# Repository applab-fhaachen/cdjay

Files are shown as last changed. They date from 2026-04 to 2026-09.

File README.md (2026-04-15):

# CDjay

## Introduction
The success of Pioneer's CDJ-Players is based on their usability and performance-oriented controls. And while the technology has evolved from CDs over SD-Cards to USB-Keys or direct interaction with a laptop, the control interface itself hasn't changed much. 
Modern CDJs, such as the CDJ-850, CDJ-900, CDJ-2000, and newer offer the possibility to directly connect to a host software, such as Algoriddim DJay, Native Instruments' Traktor, Serato Scratch, in order to be used as controller. 
The goal of this project is to bring this capability to older CDJ-Models in order to keep their control interface. 

## Related Work
A number of other projects have looked at the same idea. Some turning the CDJ into a MIDI-based controller, others integrating a RaspberryPi and running Mixxx, and open source DJ-Software on it, essentially turning them into full-blown, standalone, media-players. 

## USB-HID
The key is the USB-HID protocol which the newer models provide. Instead of registering as a USB-Midi Device, they have their own, proprietary protocol. While this conflicts with the idea of an open and flexible interface, it has the advantage of providing bi-directional communication, and thus, be able to show additional information directly on the display of the CDJ. The most common DJ software supports the HID protocol.

### Details
Technically, the CDJ registers as a USB device with a number of endpoints:
- The USB-HID interface for the control messages.
- a USB-audio interface for audio-output from the CDJ itself (relevant if you don't use the internal mixer of the software, but an external mixer). 

## Interface
Since we want to focus on interfacing the old CDJs with the modern world (USB-C, Software, etc.), we use iPad mini running Algoriddim's djay in single deck mode, which gives us all the benefits such as touch interaction, integration to streaming services, etc.. Any iPad being able to run djay is fine, although interfacing is easier with the usb-c models. 

### Installation
Install djay from the App-Store on your iPad. Technically, it is possible to run djay from an iPhone, however, it doesn't support single-deck mode on smaller devices. 

### Connecting
If you have an iPad with a lightning-connector, you need a lightning to usb-converter that supports USB OTG. This will make the iPad the host of your USB connection, and the CDJay the client. 
For the USB-Models, just connect the USB-C connection to your iPad. 

## Acknowledgements

This project was supported by...

## License
MIT License

All trademarks are property of their respective owners. This project is part of the education at FH Aachen University of Applied Sciences and not affiliated to any of the brand names.

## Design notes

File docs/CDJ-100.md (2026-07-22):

# CDJ-100
## Intro

## Board Analysis
All CDJ-100 controls (buttons, sliders, etc.) are mounted on a board that sits in the top half of the shelf and is connected to the mainboard through a 36-Pin flex cable. 

The service manual lists the following pin labels:
CN701 - CN601
Pin | I/O | Description | Use?
----|-----|-------------|-----
1  |  -  | V+5V |
2  |  I  | ADIN | Pitch slider voltage input.
3  |  I  | CT | Slider center tap voltage input.
4  | _ | GNDD|
5  | I | JOG1 | Jog Wheel Encoder. V+5V -> GNDS. Interrupt input for jog dial pulses
6  | I | JOG2 | Jog Wheel Encoder. Jog dial pulse input
7  | I |KD2 | Key return lines. Pulled High when one of the switches is pressed
8  | I | KD1 |
9  | I | KD0 |
10 | O | S12 | FL segment output
11 | O | S1 | FL segment output To HOLD (KD0), TRKB (KD1), Play (KD2) switch
12 | O | S2 | To TIME (KD0), TRKF (KD1), CUE (KD2) switch
13 | O | S3 | To EJECT (KD0), JET (KD1), SCNB (KD2) switch 
14 | O | S4 | To MT (Master Tempo) (KD0), ZIP (KD1), SCNF (KD2) switch  Connected to Flip-Flop for LED on/off
15 | O | S5 | WAH Switch to KD1
16 | O | S6 |
17 | O | S7 |
18 | O | S8 | Connected to Flip-Flop for LED on/off
19 | O | S9 | Connected to Flip-Flop for LED on/off
20 | O | S10 |
21 | O | S11 |
22 | O | G11 | FL grid output 
23 | O | G10 |
24 | O | G9 | FL grid output  
25 |  O | G8 | 
26 |  O | G7 |
27 |  O | G6 |
28 |  O | G5 |
29 |  O | G4 |
30 |  O | G3 |
31 |  O | G2 |
32 |  O | G1 | Clock Input for Flip-Flop
33 |  - | V-BV | Voltage for the Play/Cue/Disc/Window LEDs
34 |  - | AC2 | AC Voltage for the LCD (Either 5V AC or 3V AC)
35 | - | GNDS |
36 | - | AC1 | AC Voltage for the LCD

To control all that, we need 

| No.| Purpose | 
| -- | -- |
| 1  |  ADC Input| 
| 1 | CT line
| 2 | Jog Wheel |
| 3 | Button Input | 
| 11 | G-Lines |
| 12 | S-Lines | 
|  | |
| 30 | Sum | 

### Switches: 
There are 13 switches in total

S601: TRACK SEARCH (<<)
S602: SEARCH (<<)
S603: PLAY/PAUSE 
S604: TRACK SEARCH (>>)
S605: SEARCH (>>)
S606: CUE
S607: DIGITAL JOG BREAK (JET)
S608: MASTER TEMPO
S609: DIGITAL JOG BREAK (ZIP)
S610: DIGITAL JOG BREAK (WAH)
S611: EJECT 
S613: TIME MODE/AUTO CUE
S615: DIGITAL JOG BREAK (HPLD)

The Transformer Board Assembly has the following outputs:
CN705
Pin | Description | Use?
----|-------------|-----
1  | AC2 |
2  | AC1 |
3  | VLOAD | -31V for the VFD controller
4  | Audio R| The Audio connectors are located on the Transformer Board,
5  | GNDA | The Audio connectors are located on the Transformer Board,
6  | Audio L | The Audio connectors are located on the Transformer Board,
7  | CONT2 | Control Port Pins
8  | CONT1 | Control Port Pins (for Fader Start etc.)
9  | V+5V |
10 | GNDD |
11 | /RST | Comes straight from the 5V regulator output, keeps MCU off until power is stable
12 | V+BV |
13 | GNDS |
14 | V-BV |

## Display
### Pin Connection
| Pin No. | 1  | 2  | 3  | 4  | 5  | 6  | 7  | 8  | 9  | 10 | 11 | 12 | 13  | 14  | 15 | 16 | 17 | 18 | 19 | 20 | 21 | 22 | 23 | 24 | 25 | 26 | 27 | 28 | 29 | 30 | 31 | 32 | 33 | 34 | 35 | 
|---|----|----|----|----|----|----|----|----|----|----|----|----|-----|-----|----|----|----|----|----|----|----|----|----|----|----|----|----|----|----| ----|----|----|----|----|----|
| Assignment | F1 | F1 | NP | S1 | S2 | S3 | S4 | S5 | S6 | S7 | S8 | S9 | S10 | S11 | S12 | S13 | S14 | S15 | NL | NL | NL | G1 | G2 | G3 | G4 | G5 | G6 | G7 | G8 | G9 | G10 | G11 | NP | F2 | F2 |
| Signal | AC1 | AC1 | | S1 | S2 | S3| AC2 | S4 | S5 | S6 | S6 | S7 | S8 | S9 |  S3 | S10 | S11 | S12 |  NL | NL | NL | G1 | G2 | G3 | G4 | G5 | G6 | G7 | G8 | G9 | G10 | G11 | NP | AC2 | AC2 |

- F1, F2: Filament 
- S1 to S15: Anode 
- NL: No Lead
- G1 to G11: Grid
- NP: No pin

## Working Principle

### Switches
The switches are read through multplexing using the lines S1-5 as Outputs and KD0-2 as Inputs.
To figure out which switch is pressed, pull S1 high, read KD0-3, set S1 log, set S2 high, read KD0-3, set S2 Low,...

So far so good. But at the same time S1-15 are also used to drive the display, so all that needs to work with quite some refresh rate. That should be measureable by probing G1 with an oscilloscope. Yes it is, ~100Hz

### Display

The display in the CDJ-100 is a Vacuum Fluorescent Display (VFD) and these are a bit different than an LCD, which is why we need a special controller. 

The display is split in 11 grids with 12 segments.
The G1-G11 lines are used to activate the respective Grid, whose value can then be set using the S1-12 lines. Since we don't have 15, but only 12 S-Lines there needs to be a trick somewhere. 
Pin 6 and Pin 15 (S3 & S12) share the same signal S3 to form a vertical line on the 14-segment characters (G3 to G8).
Pin 10 and 11 (S7 & S8)  share the same signal S6 form a horizontal line on the 14-segment characters (G3 to G8).

Driving a VFD requires some unusual voltages. While enabling a segment is done by applying +5V, it is immediately disabled again by applying a negative bias voltage to increase contrast. The original display driver uses -30V as bias voltage. 

The PT6302 Dislpay Driver IC [Info](https://support.newhavendisplay.com/hc/en-us/articles/4414910103063-PT6302) [Datasheet](https://support.newhavendisplay.com/hc/en-us/article_attachments/4414910097047) seems to be the right choice as it offers 16 Grids and 64 Segments. The PT6312 is cheaper but can only drive 11 groups with 11 segments max, while we need 11 groups with 12 segments. 

There are some libraries out there to use these chips.
https://github.com/the-real-mcarn/PT6302
https://github.com/ysard/PT6312_VFD_Arduino_Library

The LC75710 is also a good candidate. 

The -30V Bias Voltage, luckily, comes from the trans board assy as VLOAD.

Level Conversion between RPI and Display Controller TXS0108E

#### Synchronizing with the chip for multiplexing the button readout

We need a way to synchronize with the chip in order to read out the KD-Lines. We cannot do that in parallel since the Values on the S1 to S5 depend on what's going to be shown on screen. 

However, we have some unused G-Lines from the PT6302 which we can use as trigger on the RPi. If we connect these to inputs, and set the S-Lines accordingly, we can get an interrupt, read KD0-2 and be happy. We have 16 Group outputs on the PT6302, of which only 11 are used for the display. The remaining 5, G12-G16, are connected to the RPi (don't forget the Diodes). We set the content of these groups to fixed outputs, i.e., for G12 only S1 is enabled, for G13 only S2 is enabled, ..., for G16 only G5 is enabled. This contradicts the idea of multiplexing to save pins a bit, but since we don't have a direct synchronization between the display controller and the RPi, this seems like a feasible solution. 

### LEDs
The LEDs are controlled through line S4, S8, S9 and group 1. The trick here, is that in group 1, these lines are not used, therefore ignored and can thus be used to drive the LEDs. The according segments need to be enabled disabled in the display driver. 

### Pitch Fader
The pitch fader is a classical adjustable voltage divider. At minimum, the output voltage ADIN is 0V, whereas at maximum, it is +5V. The neutral position (0%) is important in order to play tracks at their original speed. In order to compensate possible fader drift through ageing, the circuit has the CT-output. This returns a constant voltage. Connect this to an ADC to have the exact reference for ADIN at the neutral position. 

The VREF for the ADC is +5V. The GNDREF for the ADC is GNDD. 

## Connections:

I2S - Audio
SPI - Display
Encoder 
Jog-Wheel 
Pitch-Fader
KDO-KD2

### Fader Start Control
• Standard CD trigger format
° ⅛" (3.5 mm) mini TRS jacks
° Start pulse on Tip.
° Stop pulse on Ring/Sleeve.
° Normally high – Active low.
° Pulse width is 20 ms.
° Start threshold is at –65 dB of control attenuation.
° Stop threshold is at –75 dB of control attenuation.

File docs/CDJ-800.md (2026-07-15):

# CDJ-800

## Introduction
The CDJ-800 MK2, unlike the CDJ-100, but like the 200, has a dedicated board with an own controller for the switches, jog dial etc. This means that we do not need to implement an own controller circuit, but can 'just' communicate with the interface board.

## Mainboard Connectors
The Mainboard has two connectors for the CD-Player. These are not relevant for our project. We could think of adding connectors just to not have them dangling around. 
- CN102 for the spindle motor
- CN101 towards CN1101
The MAIN ASSY has two connectors relevant for our endeavour. CN301 (CD53) to the SECB ASSY and CN701 (CN801) to the JACK ASSY.

### CN301 (CK4192 - - TBB, 1MM Pitch FFC ZIF)
Pin | I/O | Description | Use?
----|-----|-------------|-----
1  |  -  | V+7M |
2  |  -  | V+7M | 
3  |  -  | V+7M | 
4  | - | GNDM |
5  | - | GNDM | 
6  | - | GNDM | 
7  | - | V+8A | (Comes from CN701) 
8  | - | V+3D |
9  | - | V+3D |
10 | - | GNDD | 
11 | - | GNDD | 
12 | - | GNDD | 
13 | - | GNDD | 
14 | - | GNDD | 
15 | - | V+6B | 
16 | - | GNDS |
17 | - | V+5P |
18 | I/O | JSDATA | 
19 | I | TSDI | Data IN
20 | I | RMIN |
21 | O | TSCS | Cable Select
22 | I/O | CONT1 | 
23 | O | TSDO | Data Out
24 | I/O | CONT2 | 
25 |  O | TSCLK | Clock

### CN701 (CK4176 - - TBB, 1MM Pitch FFC ZIF)
Pin | I/O | Description | Use?
----|-----|-------------|-----
1  |  O  | LOUT | Left audio output channel
2  |  -  | GNDA | Audio Ground
3  |  -  | GNDA | 
4  |  O  | ROUT | R audio output channel
5  | - | V+8A | 
6  | O | MUTE | Mutes the audio output
7  | -  | V-7A | 
8  | O | GNDDOUT | GND for digital audio output
9  | O | DOUT | Digital audio outpout

### Power Supply

What we we need: and I think that all comes from external, so we don't need to generate anything. (See Page 20)
V+7M 
V+8A
V+3D
V+6B
V+5P

On the regulator board, there are two ICs: IC92 and IC91. 
IC91: Takes V+6B and delivers V+3D
IC92: Takes V+10B and delivers V+7A

### References
[https://forum.arduino.cc/t/hacking-cdj800-display-communication-protocol/1133083?page=3]
[https://www.youtube.com/@edescrambler/videos]
[https://github.com/djgreeb/CDJ-1000mk3_new_life_project/blob/master/Reverse%20Engineering%20Pioneer%20CDJ-1000%20serial%20protocol.pdf]

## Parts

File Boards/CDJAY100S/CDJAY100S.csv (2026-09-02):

Reference | Qty | Value | DNP | Exclude from BOM | Exclude from Board | Footprint | Datasheet
C1,C4,C12,C13,C17,C21,C22,C23,C24 | 9 | 100 n |  |  |  | Capacitor_SMD:C_1206_3216Metric_Pad1.33x1.80mm_HandSolder
C2,C3 | 2 | 10 u |  |  |  | Capacitor_SMD:C_1206_3216Metric_Pad1.33x1.80mm_HandSolder
C5,C6 | 2 | 100 u |  |  |  | Capacitor_SMD:C_1206_3216Metric_Pad1.33x1.80mm_HandSolder
C11 | 1 | 100 n
C14,C15 | 2 | 2.2 u |  |  |  | Capacitor_SMD:C_1206_3216Metric_Pad1.33x1.80mm_HandSolder
C16 | 1 | 1 u |  |  |  | Capacitor_SMD:C_1206_3216Metric_Pad1.33x1.80mm_HandSolder
C19,C20 | 2 | 100 p |  |  |  | Capacitor_SMD:C_1206_3216Metric_Pad1.33x1.80mm_HandSolder
CN701 | 1 | 52492-3620 |  |  |  | 52045-3645:ConnectorFPC&FFC_MOL52045-3645-36P_1
CN705 | 1 | 52151-1410 |  |  |  | Connector_PinHeader_2.00mm:PinHeader_1x14_P2.00mm_Vertical
CR2 | 1 | MBR120VLSFT1G |  |  |  | Diode_SMD:Nexperia_CFP3_SOD-123W | MBR120VLSFT1G
D8,D9,D10,D11,D12,D13,D14,D15,D16 | 9 | 1SS355VM |  |  |  | Diode_SMD:Nexperia_CFP3_SOD-123W | https://fscdn.rohm.com/en/products/databook/datasheet/discrete/diode/switching/1ss355vmte-17-e.pdf
i2S_Audio1 | 1 | PCM5102 |  |  |  | Package_SO:TSSOP-20_4.4x6.5mm_P0.65mm | http://www.ti.com/lit/ds/symlink/pcm5102.pdf
J1 | 1 | Rotary Encoder |  |  |  | Connector_PinHeader_2.54mm:PinHeader_1x05_P2.54mm_Vertical
R1,R5,R9,R10,R11,R18 | 6 | 10 k |  |  |  | Resistor_SMD:R_1206_3216Metric_Pad1.30x1.75mm_HandSolder
R2,R6 | 2 | 20 k |  |  |  | Resistor_SMD:R_1206_3216Metric_Pad1.30x1.75mm_HandSolder
R3,R4 | 2 | 5 k |  |  |  | Resistor_SMD:R_1206_3216Metric_Pad1.30x1.75mm_HandSolder
R7,R8,R14,R15,R21,R22,R32,R33,R34 | 9 | 10k |  |  |  | Resistor_SMD:R_1206_3216Metric_Pad1.30x1.75mm_HandSolder
R12,R13 | 2 | 2k |  |  |  | Resistor_SMD:R_1206_3216Metric_Pad1.30x1.75mm_HandSolder
R16,R19 | 2 | 1 k |  |  |  | Resistor_SMD:R_1206_3216Metric_Pad1.30x1.75mm_HandSolder
R17 | 1 | 470 |  |  |  | Resistor_SMD:R_1206_3216Metric_Pad1.30x1.75mm_HandSolder
R20 | 1 | 82 k |  |  |  | Resistor_SMD:R_1206_3216Metric_Pad1.30x1.75mm_HandSolder
R23 | 1 | 22k |  |  |  | Resistor_SMD:R_1206_3216Metric_Pad1.30x1.75mm_HandSolder
R24,R25,R26,R27,R28,R29,R30,R31 | 8 | 22k |  |  | Excluded from board | Resistor_SMD:R_1206_3216Metric_Pad1.30x1.75mm_HandSolder
rPi1 | 1 | RaspberryPi_Pico |  |  |  | Module:RaspberryPi_Pico_Common_Unspecified | https://datasheets.raspberrypi.com/pico/pico-datasheet.pdf
U1 | 1 | PT6324Q |  |  |  | Package_QFP:QFP-52_14x14mm_P1mm_1 | file:///Users/florian/Documents/Projects/cdjay/Resources/Datasheets/PT6324.PDF
U2 | 1 | TXS0108EPW |  |  |  | Package_SO:TSSOP-20_4.4x6.5mm_P0.65mm | www.ti.com/lit/ds/symlink/txs0108e.pdf

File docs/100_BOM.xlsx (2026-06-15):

IC1 | PT6302
IC2 | TXS0108E | TI
IC3 | PCM5102A | TI |  | PCM1796 | TI
IC4
CN1 | 52045-3645 | Molex | Conrad
CN2 | 52151-1410 | Molex | Farnell
D1 | 1SS355
D2 | 1SS355
D3 | 1SS355
D4 | 1SS355
D5 | 1SS355

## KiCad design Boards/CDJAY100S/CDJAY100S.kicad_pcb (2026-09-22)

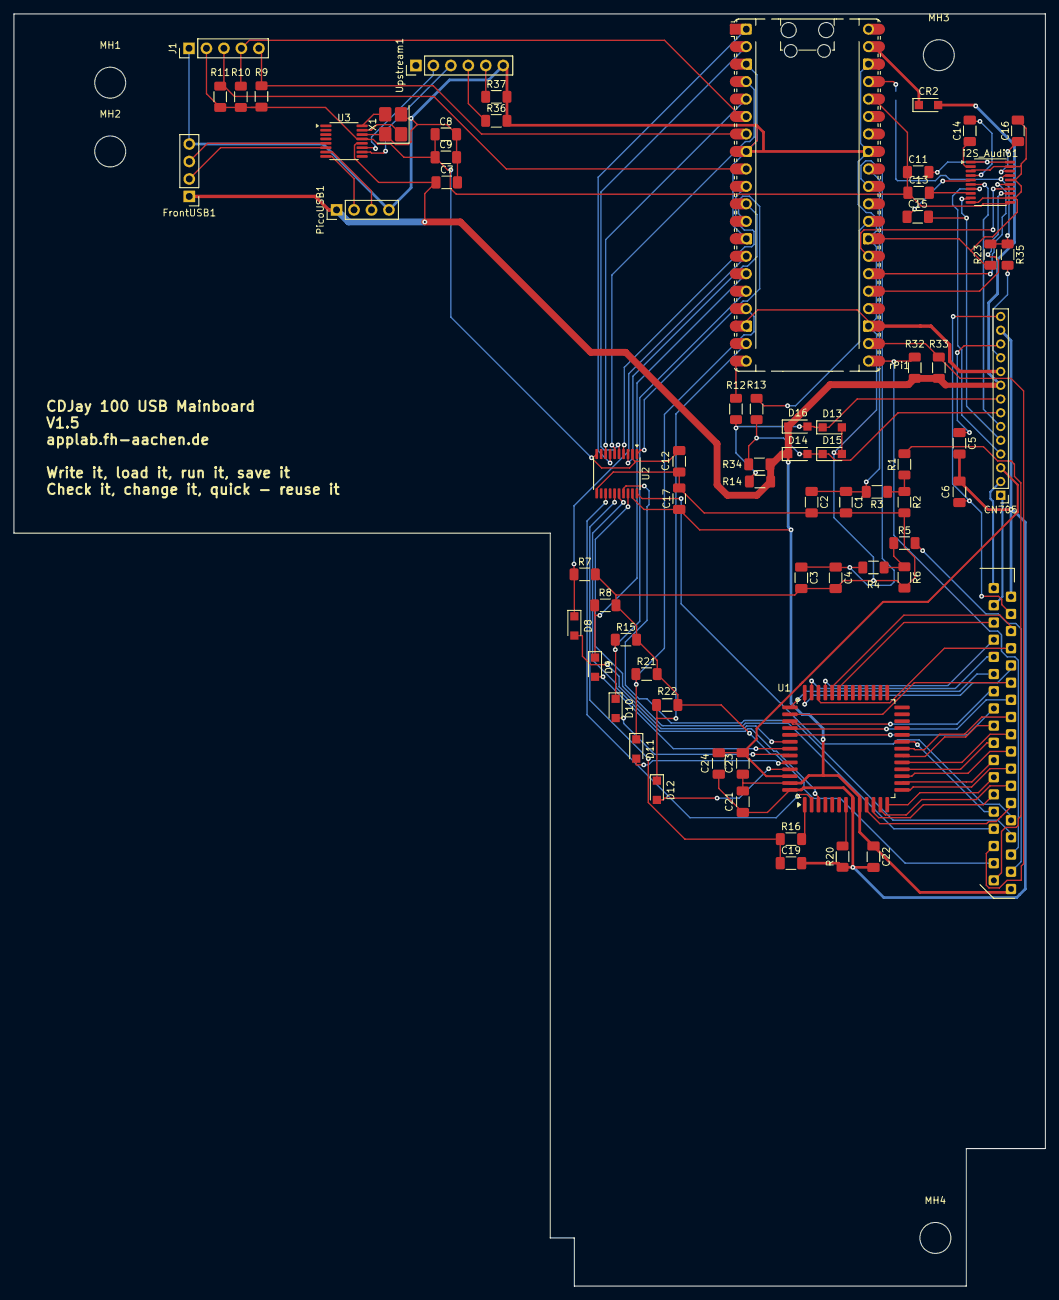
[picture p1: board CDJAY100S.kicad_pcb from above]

Board: 2 copper layers, 150.0 x 185.0 mm, 74 parts (1 on the bottom side), 98 nets.

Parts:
C1, C4, C11, C12, C13, C17, C21, C22, C23, C24: 100 n; C_1206_3216Metric_Pad1.33x1.80mm_HandSolder
C2, C3: 10 u; C_1206_3216Metric_Pad1.33x1.80mm_HandSolder
C5, C6: 100 u; C_1206_3216Metric_Pad1.33x1.80mm_HandSolder
C7, C8: 10u; C_1206_3216Metric_Pad1.33x1.80mm_HandSolder
C9: 1uf; C_1206_3216Metric_Pad1.33x1.80mm_HandSolder
C14, C15: 2.2 u; C_1206_3216Metric_Pad1.33x1.80mm_HandSolder
C16: 1 u; C_1206_3216Metric_Pad1.33x1.80mm_HandSolder
C19: 100 p; C_1206_3216Metric_Pad1.33x1.80mm_HandSolder
CN701: 52492-3620; ConnectorFPC&FFC_MOL52045-3645-36P_1
CN705: 52151-1410; PinHeader_1x14_P2.00mm_Vertical
CR2: MBR120VLSFT1G; Nexperia_CFP3_SOD-123W
D8, D9, D10, D11, D12, D13, D14, D15, D16: 1SS355VM; Nexperia_CFP3_SOD-123W
FrontUSB1: Conn_01x04_Pin; PinHeader_1x04_P2.54mm_Vertical
J1: Rotary Encoder; PinHeader_1x05_P2.54mm_Vertical
JP1: SolderJumper-2_P1.3mm_Open_Pad1.0x1.5mm
MH1, MH2, MH3, MH4: MountingHole_4.5mm
PicoUSB1: Conn_01x04_Pin; PinHeader_1x04_P2.54mm_Vertical
R1, R5, R9, R10, R11: 10 k; R_1206_3216Metric_Pad1.30x1.75mm_HandSolder
R2, R6: 20 k; R_1206_3216Metric_Pad1.30x1.75mm_HandSolder
R3, R4, R36, R37: 5.1 k; R_1206_3216Metric_Pad1.30x1.75mm_HandSolder
R7, R8, R14, R15, R21, R22, R32, R33, R34, R35: 10k; R_1206_3216Metric_Pad1.30x1.75mm_HandSolder
R12, R13: 2k; R_1206_3216Metric_Pad1.30x1.75mm_HandSolder
R16: 1 k; R_1206_3216Metric_Pad1.30x1.75mm_HandSolder
R20: 82 k; R_1206_3216Metric_Pad1.30x1.75mm_HandSolder
R23: 20k; R_1206_3216Metric_Pad1.30x1.75mm_HandSolder
U1: PT6324Q; QFP-52_14x14mm_P1mm_1
U2: TXS0108EPW; TSSOP-20_4.4x6.5mm_P0.65mm
U3: CH334R; QSOP-16_3.9x4.9mm_P0.635mm
Upstream1: Conn_01x06_Pin; PinHeader_1x06_P2.54mm_Vertical
X1: 12MHz; Crystal_SMD_3225-4Pin_3.2x2.5mm_HandSoldering
i2S_Audio1: PCM5102; TSSOP-20_4.4x6.5mm_P0.65mm
rPi1: RaspberryPi_Pico; RaspberryPi_Pico_Common_Unspecified

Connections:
+3V3: C8.1, C9.1, C11.1, C12.1, C13.1, J1.2 (+), R9.2, R10.1, R11.1, U2.2 (VCCA), U2.10 (OE), U3.13 (VDD33_{LDO}), i2S_Audio1.11 (FLT), rPi1.36 (3V3)
+5V: C7.1, C17.1, C21.1, C22.1, C23.2, CN701.1 (V+5V), CN705.9 (V+5V), CR2.2, D14.1 (K), D16.1 (K), FrontUSB1.1 (VBUS), PicoUSB1.1 (VBUS), R14.2, R32.2, R33.2, R34.2, U1.9 (VDD), U1.51 (VDD), U2.19 (VCCB), U3.12 (V5)
/ADIN: C3.1, C4.1, R4.2, rPi1.31 (GPIO26_ADC0)
/CLK: C19.1, R16.1, U2.15 (B5)
/CT: C1.1, C2.1, R3.2, rPi1.32 (GPIO27_ADC1)
/DIN: U1.2 (DIN), U2.13 (B7)
/JOG1: CN701.5 (JOG1), R32.1, rPi1.21 (GPIO16)
/JOG2: CN701.6 (JOG2), R33.1, rPi1.22 (GPIO17)
/KD0: CN701.9 (KD0), U2.20 (B1)
/SPI0 CS: U2.5 (A4), rPi1.2 (GPIO1)
/SPI0 RX: U2.7 (A6), rPi1.1 (GPIO0)
/SPI0 SCK: U2.6 (A5), rPi1.4 (GPIO2)
/SPI0 TX: U2.8 (A7), rPi1.5 (GPIO3)
/STB: U1.3 (STB), U2.16 (B4)
GND: C1.2, C2.2, C3.2, C4.2, C7.2, C8.2, C9.2, C12.2, C16.2, C17.2, CN701.4 (GNDD), CN705.10 (GNDD), D13.2 (A), D15.2 (A), FrontUSB1.4 (GND), J1.1 (GND), PicoUSB1.4 (GND), R2.2, R6.2, R7.2, R8.2, R15.2, R21.2, R22.1, R23.1, R36.2, R37.2, U2.11 (GND), U3.14 (GND), Upstream1.6 (GND), X1.2 (G), X1.4 (G), i2S_Audio1.3 (CPGND), i2S_Audio1.10 (DEMP), i2S_Audio1.12 (SCK), i2S_Audio1.16 (FMT), i2S_Audio1.19 (DGND), rPi1.3 (GND), rPi1.8 (GND), rPi1.13 (GND), rPi1.18 (GND), rPi1.23 (GND), rPi1.28 (GND), rPi1.33 (AGND), rPi1.38 (GND)
GNDA: C15.2, CN705.5 (GNDA), i2S_Audio1.9 (AGND)
GNDS: C5.2, C6.1, C19.2, C21.2, C22.2, C24.2, CN701.35 (GNDS), CN705.13 (GNDS), R20.1, U1.8 (GND), U1.52 (GND)
unnamed: CN701.36 (AC1), CN705.2 (AC1)
unnamed: CN701.34 (AC2), CN705.1 (AC2)
unnamed: CN701.2 (ADIN), R1.2
unnamed: CN701.3 (CT), R5.2
unnamed: CN701.32 (G1), U1.34 (GR1)
unnamed: CN701.31 (G2), U1.35 (GR2)
unnamed: CN701.30 (G3), U1.36 (GR3)
unnamed: CN701.29 (G4), U1.37 (GR4)
unnamed: CN701.28 (G5), U1.38 (GR5)
unnamed: CN701.27 (G6), U1.39 (GR6)
unnamed: CN701.26 (G7), U1.40 (GR7)
unnamed: CN701.25 (G8), U1.41 (GR8)
unnamed: CN701.24 (G9), U1.42 (GR9)
unnamed: CN701.23 (G10), U1.43 (GR10)
unnamed: CN701.22 (G11), U1.44 (GR11)
unnamed: CN701.8 (KD1), U2.18 (B2)
unnamed: CN701.7 (KD2), U2.17 (B3)
unnamed: CN701.11 (S1), U1.10 (SG1)
unnamed: CN701.12 (S2), U1.11 (SG2)
unnamed: CN701.13 (S3), U1.12 (SG3)
unnamed: CN701.14 (S4), U1.13 (SG4)
unnamed: CN701.15 (S5), U1.14 (SG5)
unnamed: CN701.16 (S6), U1.15 (SG6)
unnamed: CN701.17 (S7), U1.16 (SG7)
unnamed: CN701.18 (S8), U1.17 (SG8)
unnamed: CN701.19 (S9), U1.18 (SG9)
unnamed: CN701.20 (S10), U1.19 (SG10)
unnamed: CN701.21 (S11), U1.20 (SG11)
unnamed: CN701.10 (S12), U1.21 (SG12)
unnamed: CN705.6 (AUDIO_L), i2S_Audio1.6 (OUTL)
unnamed: CN705.4 (AUDIO_R), i2S_Audio1.7 (OUTR)
unnamed: CN705.8 (CONT1), D13.1 (K), D16.2 (A), R12.2, R14.1
unnamed: CN705.7 (CONT2), D14.2 (A), D15.1 (K), R13.2, R34.1
unnamed: CN705.11 (/RST), R35.2
unnamed: D8.2 (A), U1.45 (GR12)
unnamed: D8.1 (K), R7.1, rPi1.14 (GPIO10)
unnamed: D9.2 (A), U1.46 (GR13)
unnamed: D9.1 (K), R8.1, rPi1.15 (GPIO11)
unnamed: D10.2 (A), U1.47 (GR14)
unnamed: D10.1 (K), R15.1, rPi1.16 (GPIO12)
unnamed: D11.2 (A), U1.48 (GR15)
unnamed: D11.1 (K), R21.1, rPi1.17 (GPIO13)
unnamed: D12.2 (A), U1.49 (GR16)
unnamed: D12.1 (K), R22.2, rPi1.19 (GPIO14)
unnamed: FrontUSB1.2 (D+), U3.6 (DP2+)
unnamed: FrontUSB1.3 (D-), U3.5 (DM2-)
unnamed: J1.5 (CLK), R9.1, rPi1.7 (GPIO5)
unnamed: J1.4 (DT), R10.2, rPi1.6 (GPIO4)
unnamed: J1.3 (SW), R11.2, rPi1.9 (GPIO6)
unnamed: JP1.1 (A), rPi1.37 (3V3_EN)
unnamed: JP1.2 (B), R23.2, R35.1, i2S_Audio1.17 (XSMT)
unnamed: PicoUSB1.2 (D+), U3.8 (DP1+)
unnamed: PicoUSB1.3 (D-), U3.7 (DM1-)
unnamed: R1.1, R2.1, R3.1
unnamed: R4.1, R5.1, R6.1
unnamed: R16.2, U1.1 (CLK)
unnamed: R20.2, U1.7 (OSC)
unnamed: U2.1 (A1), rPi1.12 (GPIO9)
unnamed: U2.3 (A2), rPi1.11 (GPIO8)
unnamed: U2.4 (A3), rPi1.10 (GPIO7)
unnamed: U3.10 (DMU-), Upstream1.3 (D-)
unnamed: U3.11 (DPU+), Upstream1.2 (D+)
unnamed: U3.16 (XI), X1.3
unnamed: U3.15 (XO), X1.1
unnamed: R36.1, Upstream1.4 (CC1)
unnamed: R37.1, Upstream1.5 (CC2)
unnamed: C13.2, i2S_Audio1.8 (AVDD)
unnamed: i2S_Audio1.13 (BCK), rPi1.25 (GPIO19)
unnamed: C14.2, i2S_Audio1.4 (CAPM)
unnamed: C14.1, i2S_Audio1.2 (CAPP)
unnamed: C11.2, i2S_Audio1.1 (CPVDD), i2S_Audio1.20 (DVDD)
unnamed: i2S_Audio1.14 (DIN), rPi1.27 (GPIO21)
unnamed: C16.1, i2S_Audio1.18 (LDOO)
unnamed: i2S_Audio1.15 (LRCK), rPi1.26 (GPIO20)
unnamed: C15.1, i2S_Audio1.5 (VNEG)
unnamed: R12.1, rPi1.20 (GPIO15)
unnamed: R13.1, rPi1.29 (GPIO22)
unnamed: CR2.1, rPi1.39 (VSYS)
V+BV: C5.1, CN705.12 (V+BV)
V-BV: C6.2, CN701.33 (V-BV), CN705.14 (V-BV)
Vload: C23.1, C24.1, CN705.3 (VLOAD), U1.50 (VEE)

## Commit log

2026-04-24 Document the CDJ-100 Board
2026-04-28 CDJ-850 USB Device Desciptors
2026-05-05 USB Prober Application
2026-06-15 Started a BOM for the CDJ-100
    [100_BOM.xlsx]
2026-06-16 Figured out how the LEDs work
2026-07-15 Boards initial commit
    [CDJ-800.kicad_pcb, CDJ-800.kicad_sch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]
2026-07-31 Hide some details
    [CDJAY100S.kicad_pcb, CDJAY100S.kicad_sch]
2026-09-01 Revision 1.1 of the PCB and Schematics.
    [CDJAY100S.kicad_pcb, CDJAY100S.kicad_sch]
2026-09-02 Ignore Kicad Stuff
2026-09-02 CDJay Board V1.1
    Fixed:
    - Hardware Pull-Ups on G12-16
    - Power supply for Pico
    - Power supply of PT6423
    - Wired Output-Enable Pin of TSX to high
    - Clamping of Control signals to 0-5V as on the original board (can be left empty for now)
    - Connection of PCM5102 (the software libs only allow a given order)
    - Added hardware pull-ups to VLoad as on the original board in the schematic, however, they are not populated on the original board either, so they are left out of the PCB.
    - Adjusted board-geometry to fit in the case directly.
    - Fixed the Pin-Numbering and naming on the connectors to avoid any confusion.
    [CDJAY100S.csv, CDJAY100S.kicad_sch]
2026-09-10 Reorganized folder structure for the 800 board
    [CDJ-800.kicad_pcb, CDJ-800.kicad_sch]
2026-09-10 Include USB-Hub
    [CDJAY100S.kicad_pcb, CDJAY100S.kicad_sch]
2026-09-11 Board Revision 1.4
    [CDJAY100S.kicad_pcb, CDJAY100S.kicad_sch]
2026-09-22 Board Revision 1.5
    Only cosmetic changes
    - Fixed the footprint of the 36p connector to remove the bottom screen covering the copper
    - Added a solder jumper to connect the /rst pin to the pico if needed
    - moved MH3 down 0.5mm
    [CDJAY100S.kicad_pcb, CDJAY100S.kicad_sch]
2026-10-08 Old USB Prober not useful on macOS27

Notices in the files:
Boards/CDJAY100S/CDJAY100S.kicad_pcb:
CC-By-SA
